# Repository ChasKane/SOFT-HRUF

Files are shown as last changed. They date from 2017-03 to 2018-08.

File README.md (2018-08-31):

# SOFT-HRUF
This is the github page for the electronics company SoftHRUF run by Ecca Scott Urueta.
A strong contributer, ChasKane (YoungSage) designed the PCB for the company's custom
stenography keyboard.

This most recent version of the keyboard integrates a microcontroller (Atmega32U4-AU)
onto the PCB, and is split at the middle, connected by a 10p10c wire (ethernet but with 10
wires).

## Current work
Current design is in the `/Split Corded/` folder.

## Future work
We're currently contracting on a more streamlined version with bluetooth, micro SD slot, and USB-C. Contact us for more updates!

## Contact
Please direct any questions about the electronics on the Split Corded keyboard to ChasKane `LawrenceCKane@gmail.com`.
For all other questions, comments, etc. please email Scott `ecca@softhruf.love`.

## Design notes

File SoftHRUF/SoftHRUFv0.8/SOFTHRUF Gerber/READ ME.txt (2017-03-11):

---READ ME---

SoftHRUF-drl.rpt
This file is the output of KiCad's "Report Drill File" function, and lists specs about the drill file

SoftHRUF.drl
This is the drill file with the original file extension ".drl"

SoftHRUF.txt
This is a plain text file which displays the exact contents of the above "SoftHRUF.drl" file when opened in a text editor.
Note that, as stated on the wikipedia page on the Excellon format, this is not actually in Excellon format, but a similar format.
That wiki page: https://en.wikipedia.org/wiki/Excellon_format
Exact reference: https://en.wikipedia.org/wiki/Excellon_format#Excellon-like_files
Referenced statement: "The name Excellon format or Excellon file is also commonly used for files that only vaguely follow any specification. These files contain a few Excellon commands, but follow neither the Excellon nor the IPC-NC-349 specification."
I don’t know of any way that I could export this file using strict Excellon guidelines.

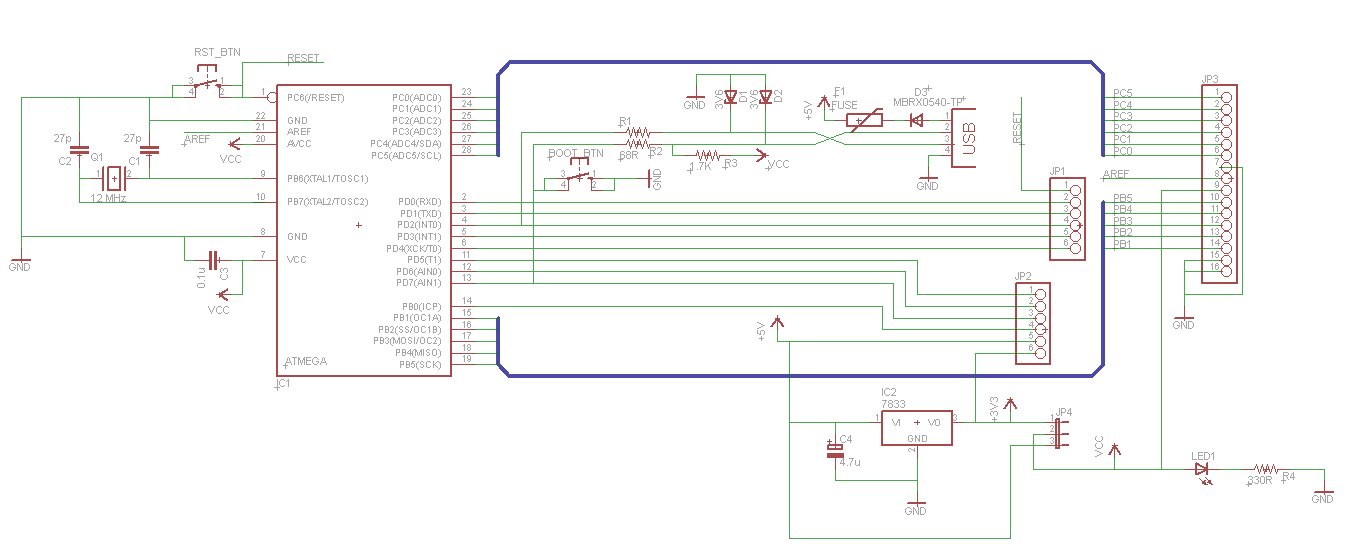
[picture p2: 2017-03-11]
Split Corded/Resources/usnoobie_sch_pic-20110115.png

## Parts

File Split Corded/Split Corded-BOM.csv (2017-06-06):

Part/Designator | Manufacture Part Number/Seeed SKU | Quantity | Description | Notes | Links | Datasheets
C1 | CC0603KRX7R9BB104 | 1 | Decoupling Cap; .1uF |  | http://www.mouser.com/Search/ProductDetail.aspx | http://www.mouser.com/ds/2/447/Yageo_UPY-GP_NP0_16V-to-50V_9-358835.pdf
C2 | GRM188R6YA106MA73D | 1 | Decoupling Cap; 10uF |  | http://www.mouser.com/Search/ProductDetail.aspx | http://www.mouser.com/ds/2/281/GRM188R6YA106MA73-01-1064796.pdf
C3 | 885012106022 | 1 | UCAP 1uF |  | http://www.mouser.com/Search/ProductDetail.aspx | http://www.mouser.com/ds/2/445/885012106022-553988.pdf
C4,C5 | CC0402JRNPO9BN100 | 2 | Crystal Caps; 10pF |  | http://www.mouser.com/Search/ProductDetail.aspx | http://www.mouser.com/ds/2/447/Yageo_UPY-GP_NP0_16V-to-50V_9-358835.pdf
CON1 | 320020027 | 1 | ICSP; 2x3
D1-D40 | MMSD4148 | 40 | Diodes |  | http://www.mouser.com/Search/ProductDetail.aspx?R=MMSD4148virtualkey51210000virtualkey512-MMSD4148 | http://www.mouser.com/ds/2/149/MMSD4148-889926.pdf
U1 | IP4234CZ6,125 | 1 | ESD Protection Module | It would be great if you could add more ESD protection options like this one into your OPL. | http://www.mouser.com/Search/ProductDetail.aspx | http://www.mouser.com/ds/2/302/IP4234CZ6-841262.pdf
U2 | ATMEGA32U4-AUR | 1 |  |  | http://www.mouser.com/Search/ProductDetail.aspx | http://www.mouser.com/ds/2/268/Atmel-7766-8-bit-AVR-ATmega16U4-32U4_Datasheet-1065717.pdf
P1 | ZX62D-B-5P8(30) | 1 | USB-B-Micro Jack |  | http://www.mouser.com/Search/ProductDetail.aspx | http://www.mouser.com/ds/2/185/ZX_catalog-939768.pdf
R1,R2 | RC0603JR-0722RL | 2 | USB Data Pull-Up Resistors |  | http://www.mouser.com/Search/ProductDetail.aspx | http://www.mouser.com/ds/2/447/RC0603-272842.pdf
R3,R4 | RC0603JR-0710KL | 2 | HWB Pull-Down and RST Pull-Up Resistors |  | http://www.mouser.com/Search/ProductDetail.aspx | http://www.mouser.com/ds/2/447/RC0603-272842.pdf
SW41 | ADTSM62RVTR | 1 | Reset Switch |  | http://www.mouser.com/Search/ProductDetail.aspx | http://www.mouser.com/ds/2/26/ADTS6-ADTSM-KTSC6-263747.pdf
Y1 | TSX-3225 16.0000MF09Z-AC3 | 1 | Crystal |  | http://www.mouser.com/Search/ProductDetail.aspx | http://www.mouser.com/ds/2/137/1721499-465440.pdf
F1 | 307010040 | 1 | resettable fuse

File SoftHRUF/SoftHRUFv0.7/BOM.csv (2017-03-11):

Part/Designator | Manufacture Part Number/Seeed SKU | Quantity
D1,D2,D3,D4,D5,D6,D7,D8,D9,D10,D11,D12,D13,D14,D15 | 304040016 | 15

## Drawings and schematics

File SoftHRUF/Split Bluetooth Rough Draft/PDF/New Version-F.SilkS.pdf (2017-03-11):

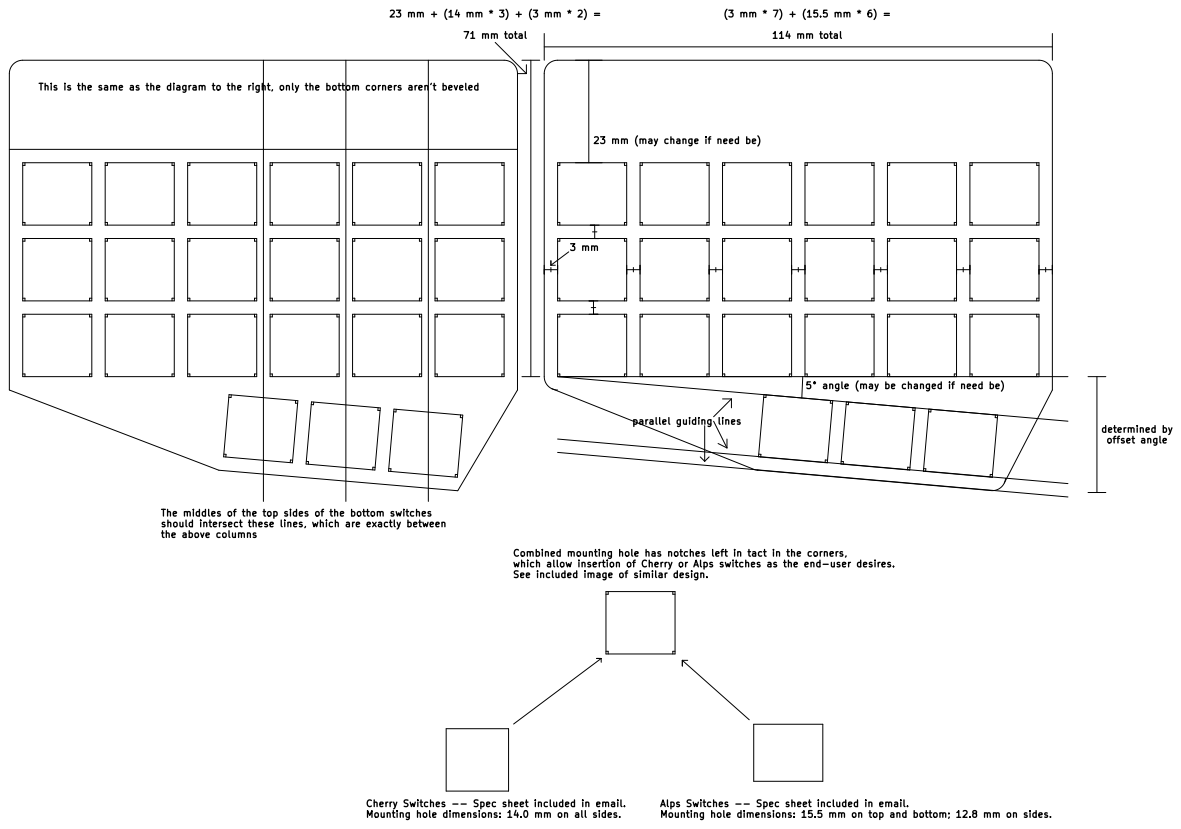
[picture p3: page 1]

114 mm total 23 mm + (14 mm * 3) + (3 mm * 2) =

This is the same as the diagram to the right, only the bottom corners aren't beveled

5° angle (may be changed if need be)

The middles of the top sides of the bottom switches
should intersect these lines, which are exactly between
the above columns

Combined mounting hole has notches left in tact in the corners,
which allow insertion of Cherry or Alps switches as the end-user desires.
See included image of similar design.

Cherry Switches -- Spec sheet included in email.
Mounting hole dimensions: 14.0 mm on all sides.

Alps Switches -- Spec sheet included in email.
Mounting hole dimensions: 15.5 mm on top and bottom; 12.8 mm on sides.

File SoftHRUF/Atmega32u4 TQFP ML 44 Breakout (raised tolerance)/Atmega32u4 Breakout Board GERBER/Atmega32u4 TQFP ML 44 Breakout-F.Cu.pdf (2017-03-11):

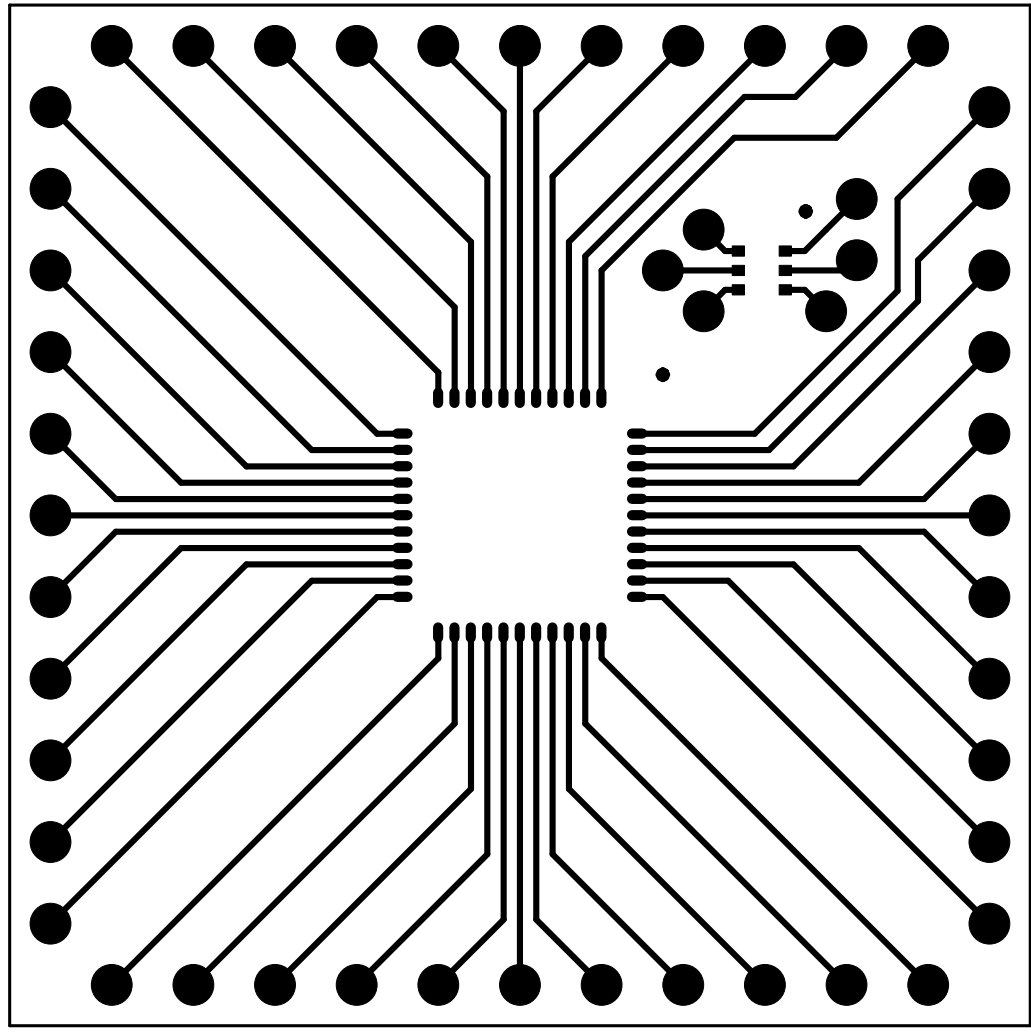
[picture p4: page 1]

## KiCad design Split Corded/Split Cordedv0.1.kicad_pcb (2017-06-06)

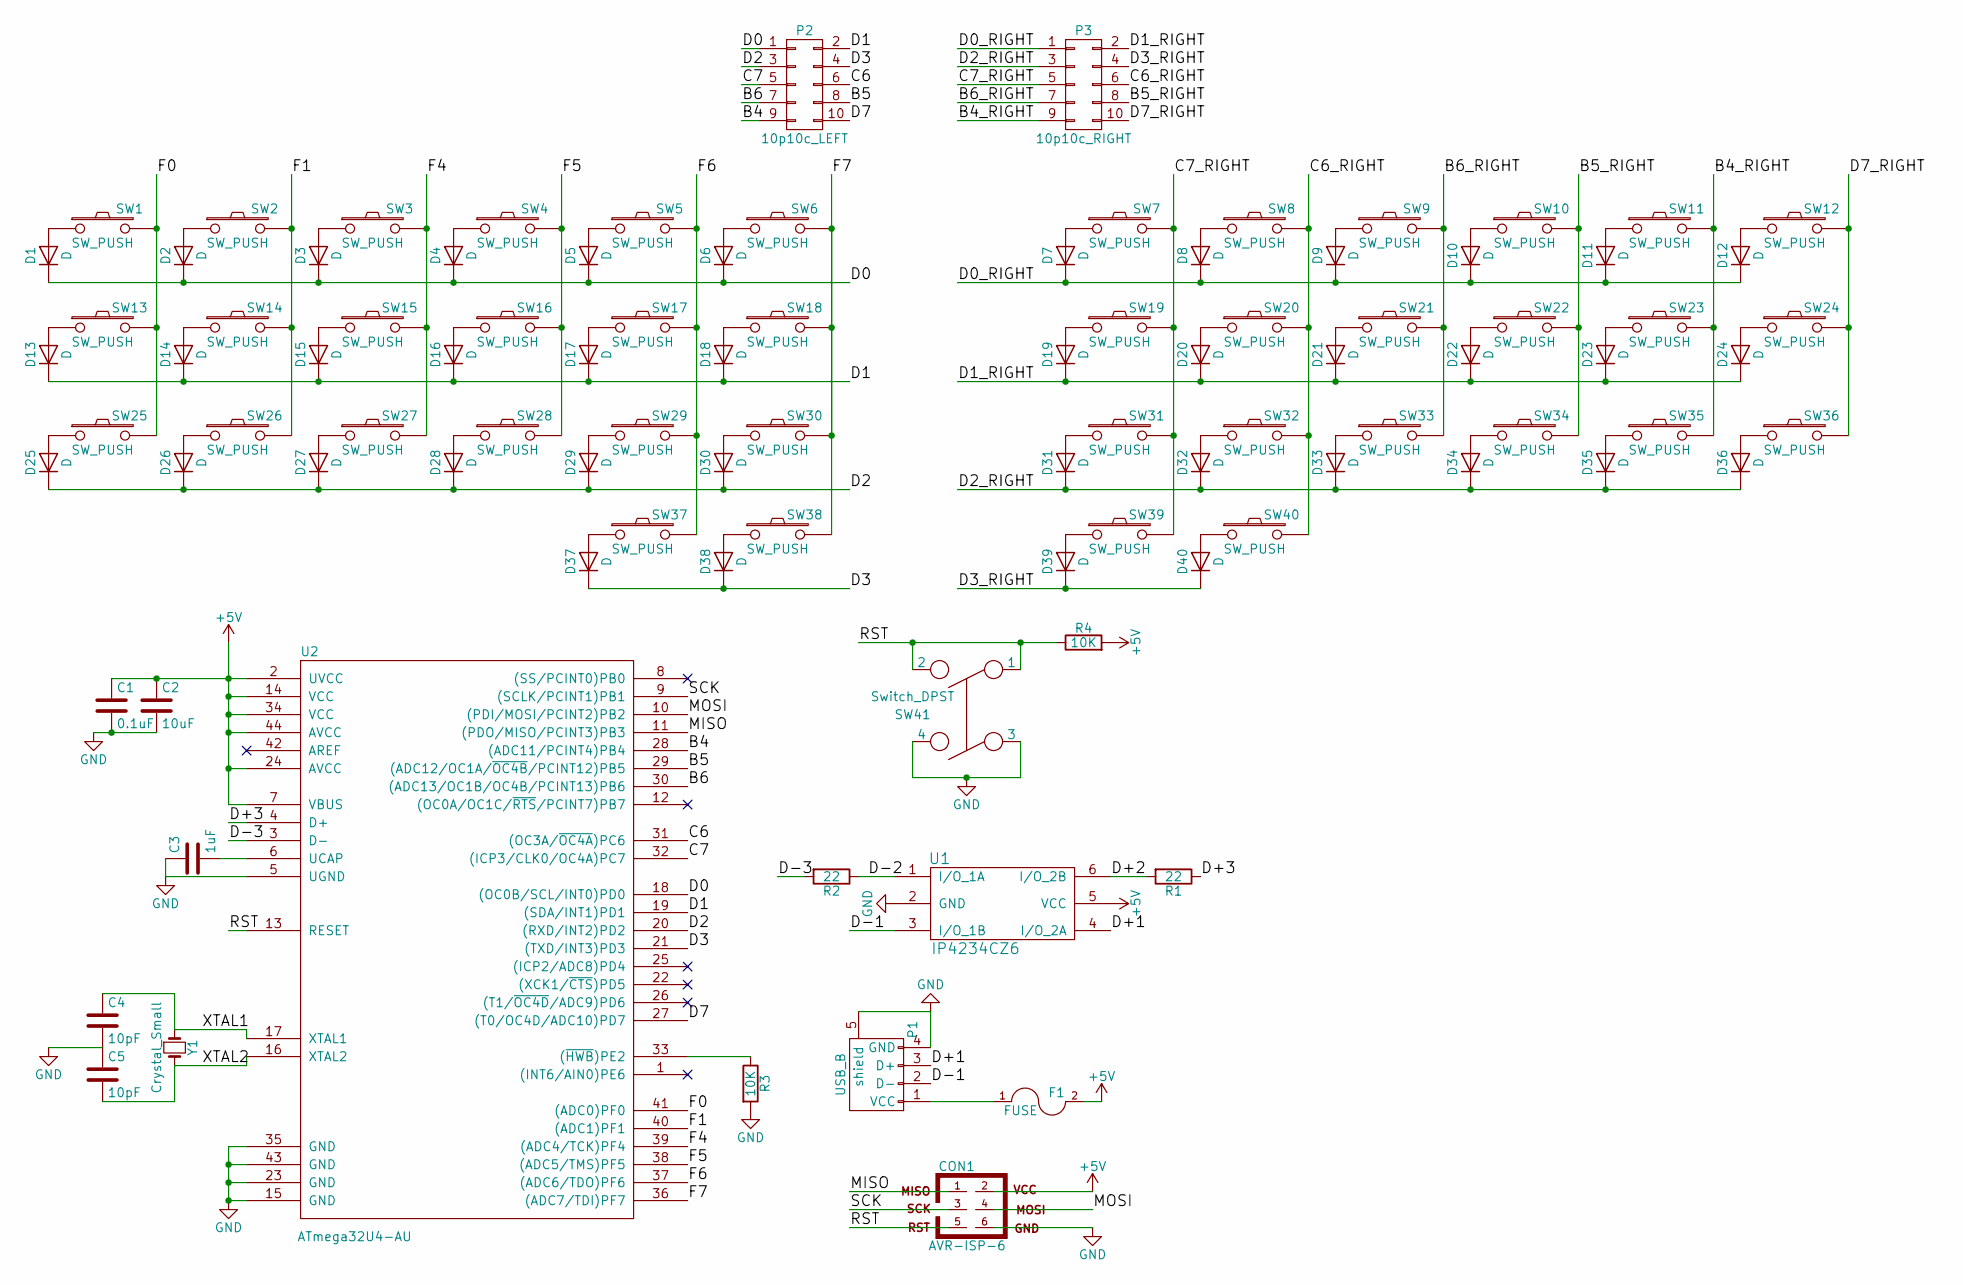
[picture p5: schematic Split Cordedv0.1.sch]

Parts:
C1: 0.1uF; C_0603
C2: 10uF; C_0603
C3: 1uF; C_0603
C4, C5: 10pF; C_0402
CON1: AVR-ISP-6; Pin_Header_Straight_2x03
D1, D2, D3, D4, D5, D6, D7, D8, D9, D10, D11, D12, D13, D14, D15, D16, D17, D18, D19, D20, D21, D22, D23, D24, D25, D26, D27, D28, D29, D30, D31, D32, D33, D34, D35, D36, D37, D38, D39, D40: D; MiniMELF_Standard
F1: FUSE; Fuse_MF-MSMF050-2
P1: USB_B; USB_Micro-B
P2: 10p10c_LEFT; 10p10c
P3: 10p10c_RIGHT; 10p10c
R1, R2: 22; R_0603
R3, R4: 10K; R_0603
SW1, SW2, SW3, SW4, SW5, SW6, SW7, SW8, SW9, SW10, SW11, SW12, SW13, SW14, SW15, SW16, SW17, SW18, SW19, SW20, SW21, SW22, SW23, SW24, SW25, SW26, SW27, SW28, SW29, SW30, SW31, SW32, SW33, SW34, SW35, SW36, SW37, SW38, SW39, SW40: SW_PUSH; SW_Matias_Quiet_With_Mounting_Hole_Frame
SW41: Switch_DPST; SMD_Button_DTSM_62K_S_V_T
U1: IP4234CZ6; SOT457
U2: ATmega32U4-AU; TQFP-44_10x10mm_Pitch0.8mm
Y1: Crystal_Small; SMD_5.0x3.2_X053201602002

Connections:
+5V: C1.1, C2.1, CON1.2, F1.2, R4.2, U1.5 (VCC), U2.2 (UVCC), U2.7 (VBUS), U2.14 (VCC), U2.24 (AVCC), U2.34 (VCC), U2.44 (AVCC)
/B4: P2.9, U2.28 ((ADC11/PCINT4)PB4)
/B4_RIGHT: P3.9, SW11.2, SW23.2, SW35.2
/B5: P2.8, U2.29 ((ADC12/OC1A/~OC4B~/PCINT12)PB5)
/B5_RIGHT: P3.8, SW10.2, SW22.2, SW34.2
/B6: P2.7, U2.30 ((ADC13/OC1B/OC4B/PCINT13)PB6)
/B6_RIGHT: P3.7, SW9.2, SW21.2, SW33.2
/C6: P2.6, U2.31 ((OC3A/~OC4A~)PC6)
/C6_RIGHT: P3.6, SW8.2, SW20.2, SW32.2, SW40.2
/C7: P2.5, U2.32 ((ICP3/CLK0/OC4A)PC7)
/C7_RIGHT: P3.5, SW7.2, SW19.2, SW31.2, SW39.2
/D0: D1.1 (K), D2.1 (K), D3.1 (K), D4.1 (K), D5.1 (K), D6.1 (K), P2.1, U2.18 ((OC0B/SCL/INT0)PD0)
/D0_RIGHT: D7.1 (K), D8.1 (K), D9.1 (K), D10.1 (K), D11.1 (K), D12.1 (K), P3.1
/D1: D13.1 (K), D14.1 (K), D15.1 (K), D16.1 (K), D17.1 (K), D18.1 (K), P2.2, U2.19 ((SDA/INT1)PD1)
/D1_RIGHT: D19.1 (K), D20.1 (K), D21.1 (K), D22.1 (K), D23.1 (K), D24.1 (K), P3.2
/D2: D25.1 (K), D26.1 (K), D27.1 (K), D28.1 (K), D29.1 (K), D30.1 (K), P2.3, U2.20 ((RXD/INT2)PD2)
/D2_RIGHT: D31.1 (K), D32.1 (K), D33.1 (K), D34.1 (K), D35.1 (K), D36.1 (K), P3.3
/D3: D37.1 (K), D38.1 (K), P2.4, U2.21 ((TXD/INT3)PD3)
/D3_RIGHT: D39.1 (K), D40.1 (K), P3.4
/D7: P2.10, U2.27 ((T0/OC4D/ADC10)PD7)
/D7_RIGHT: P3.10, SW12.2, SW24.2, SW36.2
/D+1: P1.3 (D+), U1.4 (I/O_2A)
/D+2: R1.2, U1.6 (I/O_2B)
/D+3: R1.1, U2.4 (D+)
/D-1: P1.2 (D-), U1.3 (I/O_1B)
/D-2: R2.1, U1.1 (I/O_1A)
/D-3: R2.2, U2.3 (D-)
/F0: SW1.2, SW13.2, SW25.2, U2.41 ((ADC0)PF0)
/F1: SW2.2, SW14.2, SW26.2, U2.40 ((ADC1)PF1)
/F4: SW3.2, SW15.2, SW27.2, U2.39 ((ADC4/TCK)PF4)
/F5: SW4.2, SW16.2, SW28.2, U2.38 ((ADC5/TMS)PF5)
/F6: SW5.2, SW17.2, SW29.2, SW37.2, U2.37 ((ADC6/TDO)PF6)
/F7: SW6.2, SW18.2, SW30.2, SW38.2, U2.36 ((ADC7/TDI)PF7)
/MISO: CON1.1, U2.11 ((PDO/MISO/PCINT3)PB3)
/MOSI: CON1.4, U2.10 ((PDI/MOSI/PCINT2)PB2)
/RST: CON1.5, R4.1, SW41.1, SW41.2, U2.13 (RESET)
/SCK: CON1.3, U2.9 ((SCLK/PCINT1)PB1)
/XTAL1: C4.1, U2.17 (XTAL1), Y1.1
unnamed: C3.2, U2.6 (UCAP)
unnamed: D1.2 (A), SW1.1
unnamed: D2.2 (A), SW2.1
unnamed: D3.2 (A), SW3.1
unnamed: D4.2 (A), SW4.1
unnamed: D5.2 (A), SW5.1
unnamed: D6.2 (A), SW6.1
unnamed: D7.2 (A), SW7.1
unnamed: D8.2 (A), SW8.1
unnamed: D9.2 (A), SW9.1
unnamed: D10.2 (A), SW10.1
unnamed: D11.2 (A), SW11.1
unnamed: D12.2 (A), SW12.1
unnamed: D13.2 (A), SW13.1
unnamed: D14.2 (A), SW14.1
unnamed: D15.2 (A), SW15.1
unnamed: D16.2 (A), SW16.1
unnamed: D17.2 (A), SW17.1
unnamed: D18.2 (A), SW18.1
unnamed: D19.2 (A), SW19.1
unnamed: D20.2 (A), SW20.1
unnamed: D21.2 (A), SW21.1
unnamed: D22.2 (A), SW22.1
unnamed: D23.2 (A), SW23.1
unnamed: D24.2 (A), SW24.1
unnamed: D25.2 (A), SW25.1
unnamed: D26.2 (A), SW26.1
unnamed: D27.2 (A), SW27.1
unnamed: D28.2 (A), SW28.1
unnamed: D29.2 (A), SW29.1
unnamed: D30.2 (A), SW30.1
unnamed: D31.2 (A), SW31.1
unnamed: D32.2 (A), SW32.1
unnamed: D33.2 (A), SW33.1
unnamed: D34.2 (A), SW34.1
unnamed: D35.2 (A), SW35.1
unnamed: D36.2 (A), SW36.1
unnamed: D37.2 (A), SW37.1
unnamed: D38.2 (A), SW38.1
unnamed: D39.2 (A), SW39.1
unnamed: D40.2 (A), SW40.1
unnamed: F1.1, P1.1 (VCC)
unnamed: R3.1, U2.33 ((~HWB~)PE2)

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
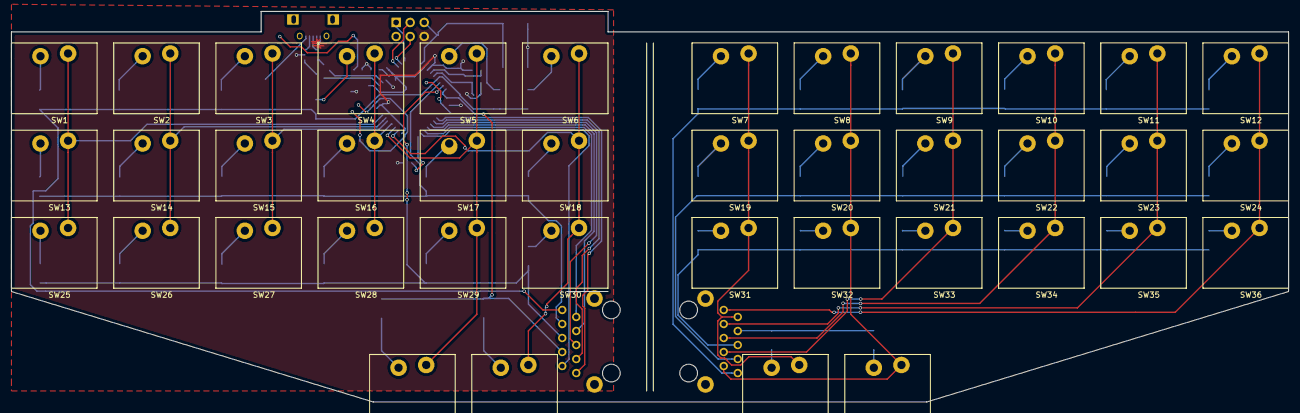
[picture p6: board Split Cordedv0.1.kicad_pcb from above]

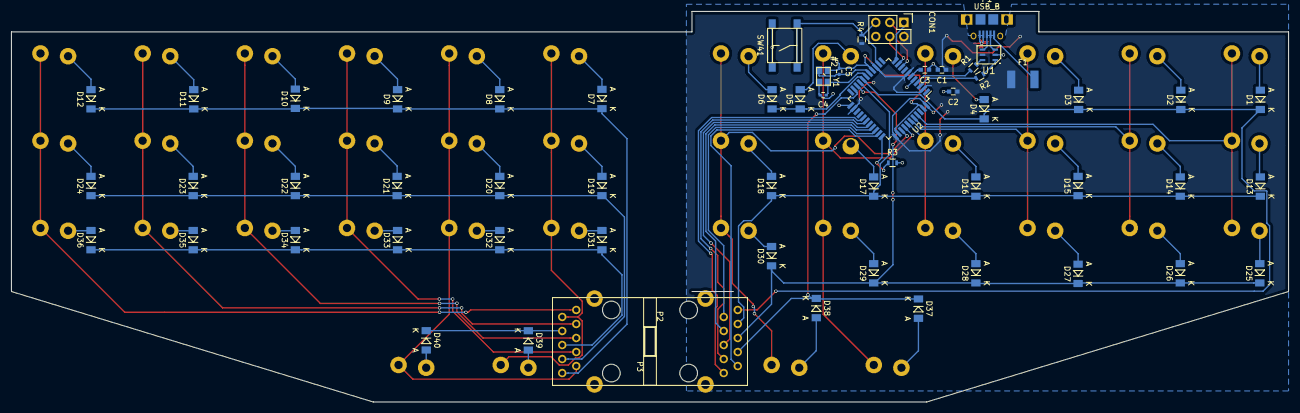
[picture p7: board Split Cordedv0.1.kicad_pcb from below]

Board: 2 copper layers, 231.2 x 70.7 mm, 98 parts (58 on the bottom side), 83 nets.

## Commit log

2017-03-11 Split Keyboard
    This is everything to date; future updates will be made using GitHub,
    such as the possible bluetooth version.
    [Atmega32u4 TQFP ML 44 Breakout-B.Adhes.gbr, Atmega32u4 TQFP ML 44 Breakout-B.CrtYd.gbr, Atmega32u4 TQFP ML 44 Breakout-B.Cu.gbr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]
2017-03-28 Still trying to get the moved interconnect back
    [Atmega32u4 TQFP ML 44 Breakout-B.Adhes.gbr, Atmega32u4 TQFP ML 44 Breakout-B.CrtYd.gbr, Atmega32u4 TQFP ML 44 Breakout-B.Cu.gbr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]
2017-03-28 Should be good now
    Apparently, I had the most updated files on my external. Now everything
    is in one place!
    [Atmega32u4 TQFP ML 44 Breakout-B.Adhes.gbr, Atmega32u4 TQFP ML 44 Breakout-B.CrtYd.gbr, Atmega32u4 TQFP ML 44 Breakout-B.Cu.gbr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]
2017-03-28 All connections checked, all ground and VCC connections specifically. Awaiting final tests in the lab on current prototype before finalizing.
    [Split Cordedv0.1.kicad_pcb]
2017-03-30 In the middle of making last few changes. Last thing I need to do is fiddle with the USB connector, since the first one showed signs of weakness.
    [Split Cordedv0.1.kicad_pcb, Split Cordedv0.1.sch]
2017-06-06 pushing everything to github for the summer -- I won't have time to work on this :/
    [Atmega32u4 TQFP ML 44 Breakout-B.Adhes.gbr, Atmega32u4 TQFP ML 44 Breakout-B.CrtYd.gbr, Atmega32u4 TQFP ML 44 Breakout-B.Cu.gbr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]

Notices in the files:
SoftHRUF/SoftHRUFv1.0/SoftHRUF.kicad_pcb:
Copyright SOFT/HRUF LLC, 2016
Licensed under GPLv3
